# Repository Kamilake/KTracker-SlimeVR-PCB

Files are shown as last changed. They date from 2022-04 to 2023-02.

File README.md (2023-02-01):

# Move to the [FineMotion!](https://github.com/Kamilake/FineMotion-Tracker)
This repo is old and I created a new tracker. For non-maintenance purposes, go to:   
https://github.com/Kamilake/FineMotion-Tracker

# KTracker-SlimeVR-PCB
ESP8266 Attitude Tracker for SlimeVR

Full SMT PCB operating in MPU-6050 + QMC5883L 9DoF mode (or any breakout board compatible with GY-521)

Operate with all 5V chargers, including C to C PD chargers.

You can use it simply by ordering it from the fabricator

M.2 SSD size ultra-small form factor, Smallest size that can fit 18650!

FBT_Round_2022-Feb-21_12-32-22AM-000_CustomizedView14755583882_png - 복사본
KakaoTalk_20220223_222725417_01
KakaoTalk_20220223_222725417


KakaoTalk_20220420_084354356_01
KakaoTalk_20220726_093847052

## Available Battery

You can use any battery if you don't use the included modeling. or
1. 052050,052070,102050,102070 Size Li-Po (1000mAh) with JST PH 2.0mm Connector
2. 18650 battery (up to 4200mAh) with THT PIN 18650 Battery holder
3. 3x 1.5v battery (cannot be charged)

## Available Equipment 

## License
**This hardware is licensed under the CERN-OHL-P v2 license**, which is a permissive,
non-viral and non-reciprocal open hardware license. Unlike software licenses like
MIT and Apache 2.0, it better handles the nuances of hardware and protects both
the licensor and licensee from patent lawsuits.

**Unless you explicitly state otherwise, any contribution intentionally submitted
for inclusion in this work by you, shall be licensed as above, without any
additional terms or conditions.**

### Conveying notice of License
Note that as part of the CERN-OHL-P v2 license, recipients of manufactured
hardware must also receive notice of the above license. One such
method of conveying the notice is to include a link to the original source repo,
or printing "Licensed under CERN-OHL-P v2" on the PCB silkscreen. For more info,
see [here](https://ohwr.org/project/cernohl/wikis/Documents/CERN-OHL-version-2).

This is conceptually similar to the MIT/Apache 2.0 Licenses, where the original
license must still be included as a notice even when the source is modified and
subsequently relicensed under different terms.

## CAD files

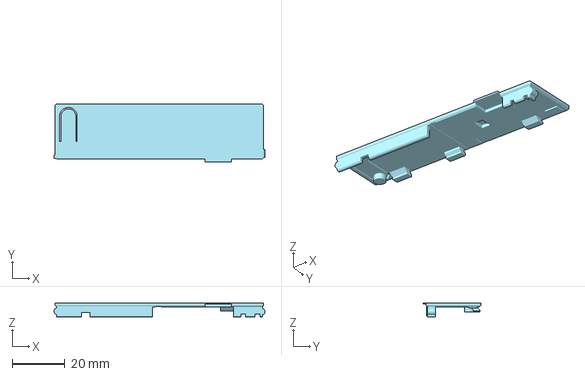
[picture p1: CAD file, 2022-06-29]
3D Models/FBT_Round2 v30 Cover.3mf
79.9 x 21.8 x 5.40 mm

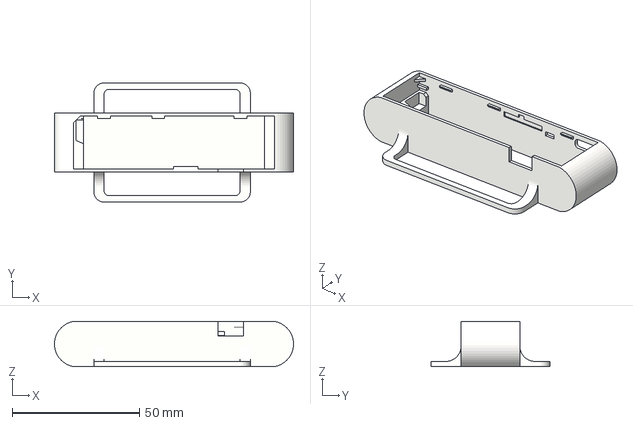
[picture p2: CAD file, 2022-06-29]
3D Models/FBT_Round2 v31 Chassis.3mf
93.8 x 46.8 x 17.7 mm

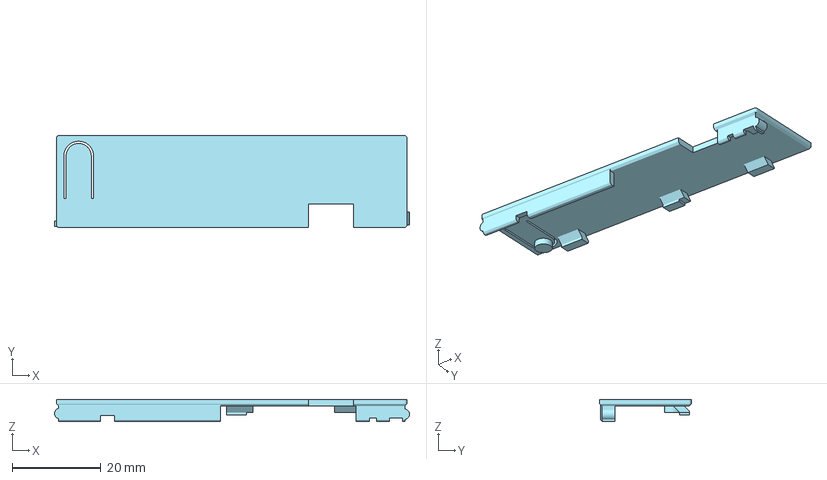
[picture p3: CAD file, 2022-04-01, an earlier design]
3D Models/FBT_Round2 v23 Cover.3mf
79.9 x 20.7 x 5.00 mm

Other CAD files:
3D Models/FBT_Round2 v23 Chassis.3mf

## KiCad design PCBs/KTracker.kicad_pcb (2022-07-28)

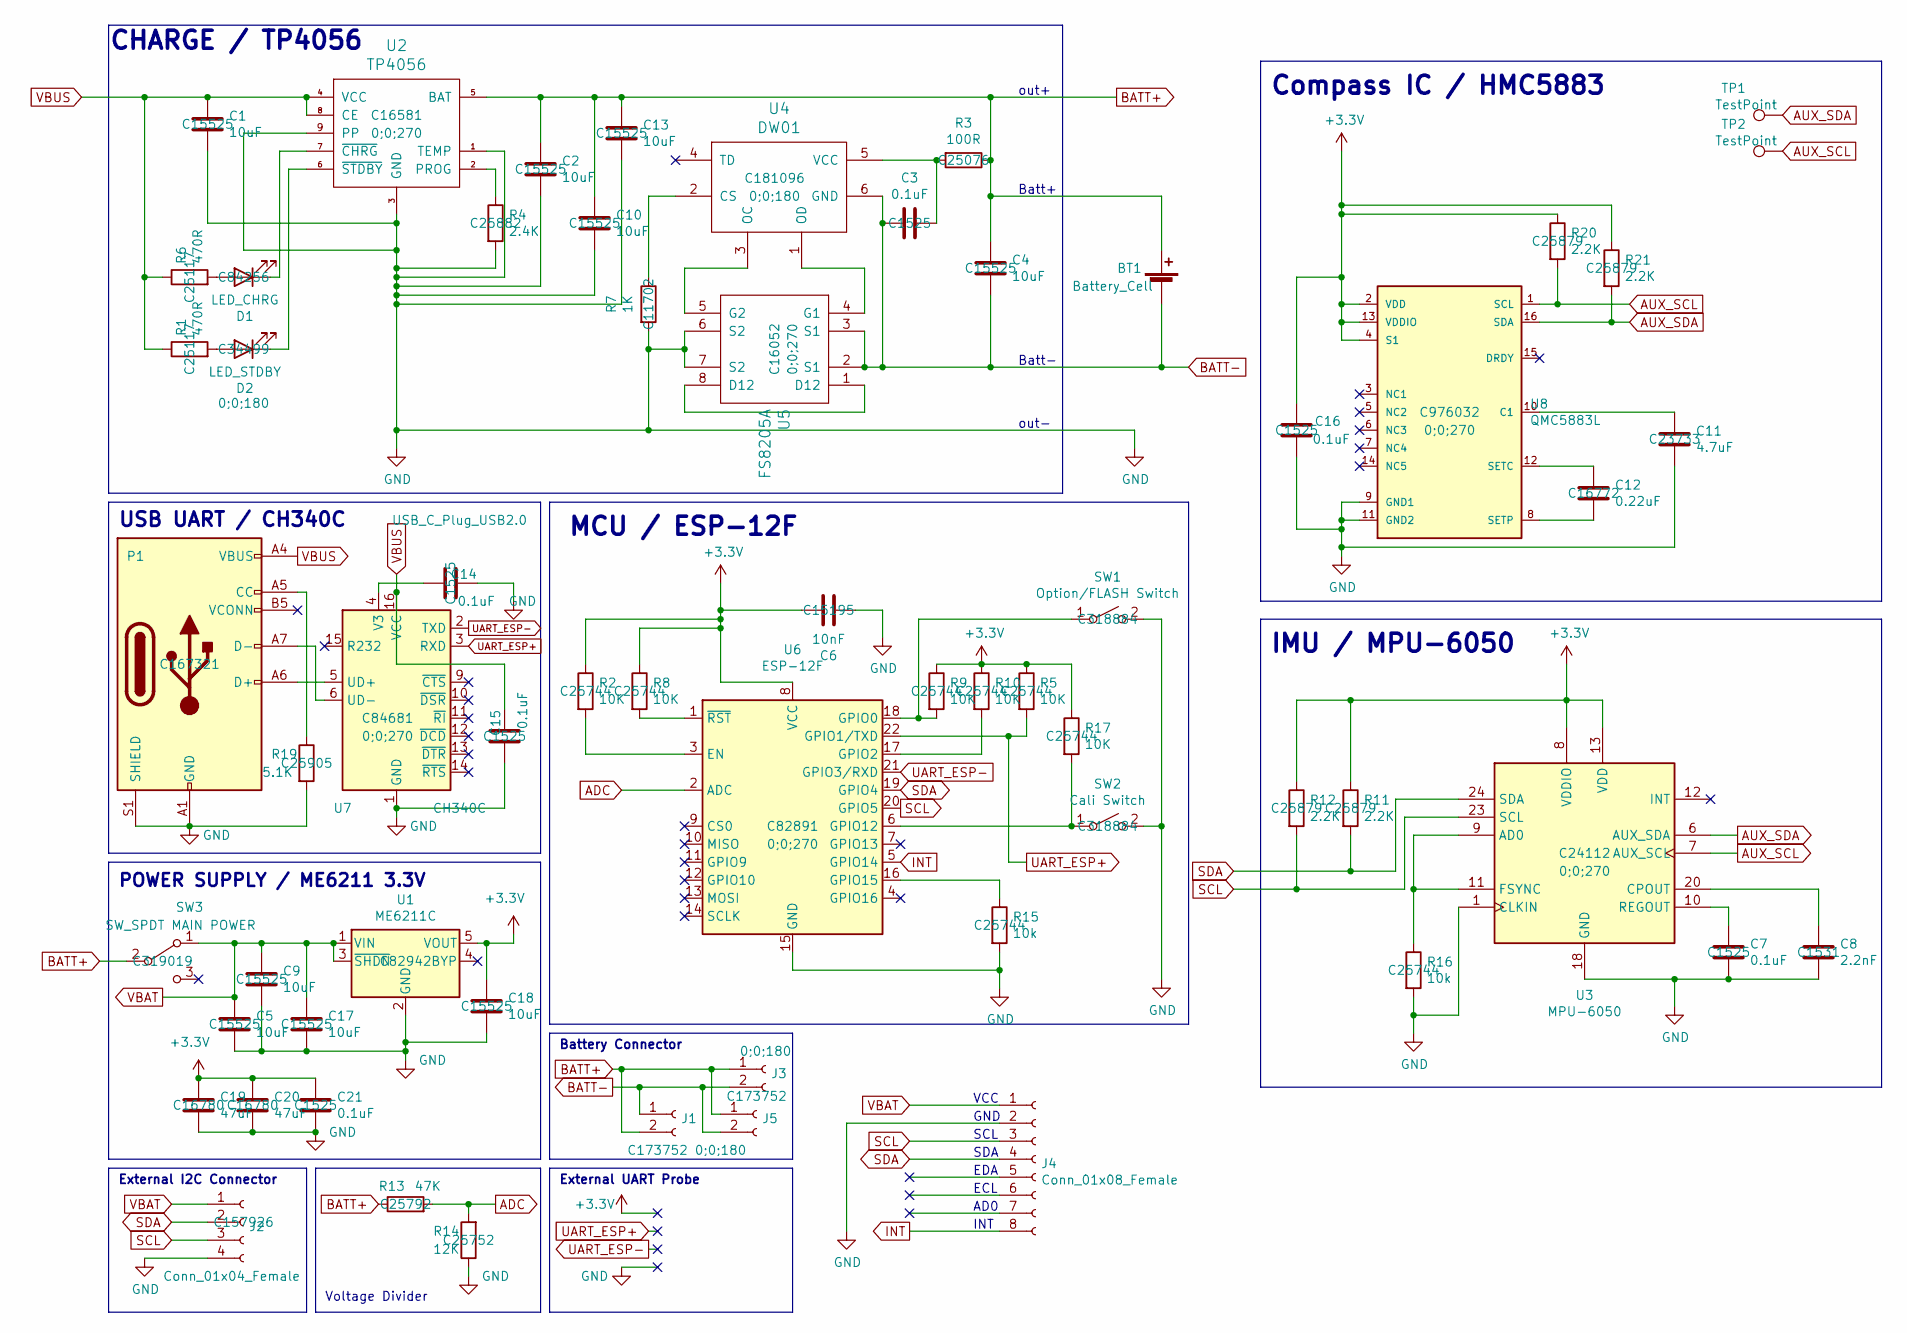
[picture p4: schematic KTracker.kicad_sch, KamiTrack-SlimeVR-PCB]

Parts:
BT1: Battery_Cell; BatteryHolder_MPD_BH-18650-PC2
C1, C2, C4, C5, C9, C10, C13, C17, C18: 10uF; C_0402_1005Metric; LCSC C15525
C3, C7, C14, C15, C16, C21: 0.1uF; C_0402_1005Metric; LCSC C1525
C6: 10nF; C_0402_1005Metric; LCSC C15195
C8: 2.2nF; C_0402_1005Metric; LCSC C1531
C11: 4.7uF; C_0402_1005Metric; LCSC C23733
C12: 0.22uF; C_0402_1005Metric; LCSC C16772
C19, C20: 47uF; C_0805_2012Metric; LCSC C16780
D1: LED_CHRG; LED_0805_2012Metric; LCSC C84256
D2: LED_STDBY; LED_0805_2012Metric; LCSC C34499
J1, J3: Conn_01x02_Female; JST_PH_S2B-PH-K_1x02_P2.00mm_Horizontal; LCSC C173752
J2: Conn_01x04_Female; JST_PH_S4B-PH-K_1x04_P2.00mm_Horizontal; LCSC C157926
J4: Conn_01x08_Female; PinSocket_1x08_P2.54mm_Vertical
J5: Conn_01x02_Female; MOLEX_532610271
P1: USB_C_Plug_USB2.0; USB_C_Receptacle_HRO_TYPE-C-31-M-12; LCSC C167321
R1, R6: 470R; R_0402_1005Metric; LCSC C25117
R2, R5, R8, R9, R10, R17: 10K; R_0402_1005Metric; LCSC C25744
R3: 100R; R_0402_1005Metric; LCSC C25076
R4: 2.4K; R_0402_1005Metric; LCSC C25882
R7: 1K; R_0402_1005Metric; LCSC C11702
R11, R12, R20, R21: 2.2K; R_0402_1005Metric; LCSC C25879
R13: 47K; R_0402_1005Metric; LCSC C25792
R14: 12K; R_0402_1005Metric; LCSC C25752
R15, R16: 10k; R_0402_1005Metric; LCSC C25744
R19: 5.1K; R_0402_1005Metric; LCSC C25905
SW1: Option/FLASH Switch; SW_SPST_SKQG_WithoutStem; LCSC C318884
SW2: Cali Switch; SW_SPST_SKQG_WithoutStem; LCSC C318884
SW3: SW_SPDT MAIN POWER; SW_SPDT_PCM12; LCSC C319019
TP1, TP2: TestPoint; TestPoint_Pad_D1.0mm
U1: ME6211C; SOT-23-5; LCSC C82942
U2: TP4056; HSOP-8-1EP_3.9x4.9mm_P1.27mm_EP2.41x3.1mm_ThermalVias; LCSC C16581
U3: MPU-6050; InvenSense_QFN-24_4x4mm_P0.5mm; LCSC C24112
U4: DW01; SOT-23-6_Handsoldering; LCSC C181096
U5: FS8205A; TSSOP-8_4.4x3mm_P0.65mm; LCSC C16052
U6: ESP-12F; ESP-12E; LCSC C82891
U7: CH340C; SOIC-16_3.9x9.9mm_P1.27mm; LCSC C84681
U8: QMC5883L; LGA-16_3x3mm_P0.5mm; LCSC C976032

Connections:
+3V3: C6.1, C16.2, C18.1, C19.1, C20.1, C21.1, R2.1, R5.1, R8.1, R9.1, R10.1, R11.1, R12.1, R17.1, R20.1, R21.1, U1.5 (VOUT), U3.8 (VDDIO), U3.13 (VDD), U6.8 (VCC), U8.2 (VDD), U8.4 (S1), U8.13 (VDDIO); also elsewhere on the board
ADC: R13.2, R14.2, U6.2 (ADC)
AUX_SCL: R20.2, TP2.1, U3.7 (AUX_SCL), U8.1 (SCL)
AUX_SDA: R21.2, TP1.1, U3.6 (AUX_SDA), U8.16 (SDA)
BATT+: BT1.1 (+), C2.1, C4.1, C10.1, C13.1, J1.2, J3.1, J5.1, R3.1, R13.1, SW3.2 (B), U2.5 (BAT)
BATT-: BT1.2 (-), C3.2, C4.2, J1.1, J3.2, J5.2, U4.6 (GND), U5.2 (S1), U5.3 (S1)
GND: C1.2, C2.2, C5.2, C6.2, C7.2, C8.2, C9.2, C10.2, C11.2, C13.2, C14.2, C15.1, C16.1, C17.2, C18.2, C19.2, C20.2, C21.2, J2.4, J4.2, P1.A1 (GND), P1.A12 (GND), P1.B1 (GND), P1.B12 (GND), P1.S1 (SHIELD), R4.2, R7.2, R14.1, R15.2, R16.2, R19.2, SW1.2 (B), SW2.2 (B), U1.2 (GND), U2.1 (TEMP), U2.3 (GND), U2.9 (PP), U3.1 (CLKIN), U3.18 (GND), U5.6 (S2), U5.7 (S2), U6.15 (GND), U7.1 (GND), U8.9 (GND1), U8.11 (GND2); also elsewhere on the board
INT: J4.8, U6.5 (GPIO14)
unnamed: C3.1, R3.2, U4.5 (VCC)
unnamed: C7.1, U3.10 (REGOUT)
unnamed: C8.1, U3.20 (CPOUT)
unnamed: C11.1, U8.10 (C1)
unnamed: C12.1, U8.12 (SETC)
unnamed: C12.2, U8.8 (SETP)
unnamed: C14.1, U7.4 (V3)
unnamed: D1.1 (K), U2.7 (~CHRG)
unnamed: D1.2 (A), R6.2
unnamed: D2.1 (K), U2.6 (~STDBY)
unnamed: D2.2 (A), R1.2
unnamed: P1.A5 (CC), R19.1
unnamed: P1.A6 (D+), U7.5 (UD+)
unnamed: P1.A7 (D-), U7.6 (UD-)
unnamed: R2.2, U6.3 (EN)
unnamed: R4.1, U2.2 (PROG)
unnamed: R7.1, U4.2 (CS)
unnamed: R8.2, U6.1 (~RST)
unnamed: R9.2, SW1.1 (A), U6.18 (GPIO0)
unnamed: R10.2, U6.17 (GPIO2)
unnamed: R15.1, U6.16 (GPIO15)
unnamed: R16.1, U3.9 (AD0), U3.11 (FSYNC)
unnamed: R17.2, SW2.1 (A), U6.6 (GPIO12)
unnamed: U4.1 (OD), U5.4 (G1)
unnamed: U4.3 (OC), U5.5 (G2)
unnamed: U5.1 (D12), U5.8 (D12)
SCL: J2.3, J4.3, R12.2, U3.23 (SCL), U6.20 (GPIO5)
SDA: J2.2, J4.4, R11.2, U3.24 (SDA), U6.19 (GPIO4)
UART_ESP+: R5.2, U6.22 (GPIO1/TXD), U7.3 (RXD)
UART_ESP-: U6.21 (GPIO3/RXD), U7.2 (TXD)
VBAT: C5.1, C9.1, C17.1, J2.1, J4.1, SW3.1 (A), U1.1 (VIN), U1.3 (~SHDN)
VBUS: C1.1, C15.2, P1.A4 (VBUS), P1.A9 (VBUS), P1.B4 (VBUS), P1.B9 (VBUS), R1.1, R6.1, U2.4 (VCC), U2.8 (CE), U7.16 (VCC)

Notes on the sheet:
Voltage Divider
Batt-
External UART Probe
MCU / ESP-12F
External I2C Connector
AD0
IMU / MPU-6050
Compass IC / HMC5883
POWER SUPPLY / ME6211 3.3V
ECL
out+
GND
EDA
VCC
SDA
INT
Batt+
CHARGE / TP4056
USB UART / CH340C
Battery Connector
out-
SCL

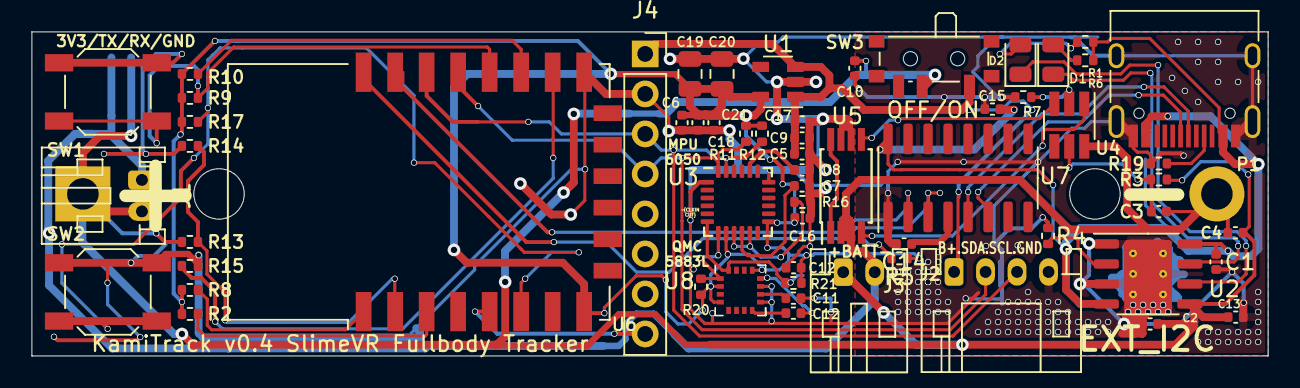
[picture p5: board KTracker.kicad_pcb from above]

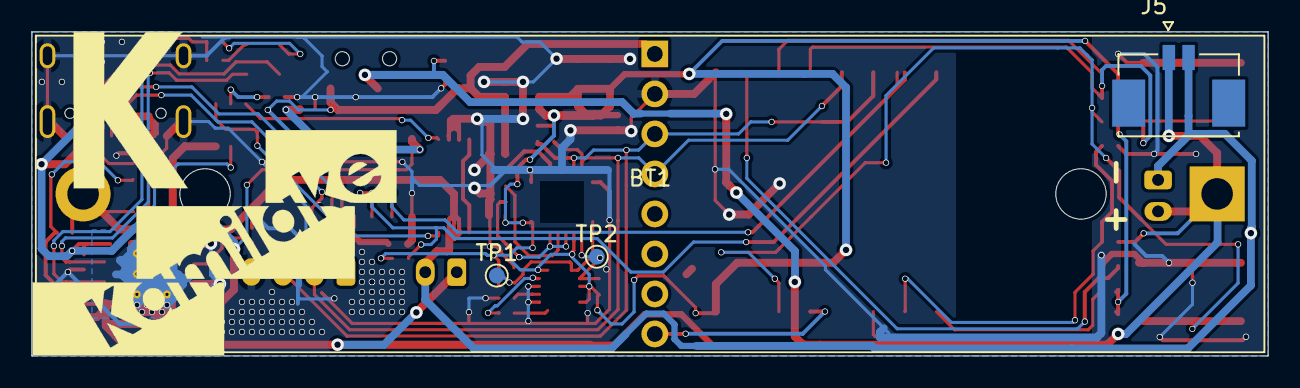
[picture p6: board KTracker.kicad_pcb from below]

Board: 2 copper layers, 78.5 x 20.6 mm, 64 parts (4 on the bottom side), 40 nets.

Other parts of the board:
C12#2: 0.1uF; C_0402_1005Metric

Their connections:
+3V3: C12#2.1; also elsewhere on the board
GND: C12#2.2; also elsewhere on the board

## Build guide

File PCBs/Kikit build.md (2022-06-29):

# Custom assembly using Kikit

## Panalize and Fab
```batch
kikit panelize ^
    -p :jlcTooling ^
    --layout "grid; rows: 5; cols: 10;" ^
    --source "tolerance: 1000mm" ^
    --tabs full ^
    --cuts vcuts ./KamiTrack.kicad_pcb ^
    KamiTrack_panel.kicad_pcb

kikit fab jlcpcb ^
    --assembly ^
    --schematic ./KamiTrack.kicad_sch ^
    --ignore J1 ^
    --no-drc ./KamiTrack_panel.kicad_pcb ^
    ./fab
```

## Only Fab

### Using internal MPU-6050 and bottom Lipo
```batch
kikit fab jlcpcb ^
    --assembly ^
    --schematic ./KamiTrack.kicad_sch ^
    --ignore BT1,J3,J4,J5 ^
    --no-drc ./KamiTrack.kicad_pcb ^
    "./Gerber/Using internal MPU-6050"

```

### Using GY-521 and bottom Lipo
```batch
kikit fab jlcpcb ^
    --assembly ^
    --schematic ./KamiTrack.kicad_sch ^
    --ignore U8,U3,R20,R21,C16,C12,C11,R12,R11,BT1,J3,J4,J5 ^
    --no-drc ./KamiTrack.kicad_pcb ^
    "./Gerber/Using GY-521"

```

### Using GY-521 and 18650
```batch
kikit fab jlcpcb ^
    --assembly ^
    --schematic ./KamiTrack.kicad_sch ^
    --ignore U8,U3,R20,R21,C16,C12,C11,R12,R11,J1,J3,J4,J5 ^
    --no-drc ./KamiTrack.kicad_pcb ^
    "./Gerber/Using GY-521"

```

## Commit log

2022-04-01 Add 3D Models
    [FBT_Round2 v23 Chassis.3mf, FBT_Round2 v23 Cover.3mf]
2022-04-06 pcb thickness 1.6->1.2
    [KamiTrack.kicad_pcb]
2022-04-07 Added sheet description
    [KamiTrack.kicad_sch]
2022-06-29 custom assembly guide
2022-06-29 Left side Lipo
2022-06-29 Standby LED Change to C34499
    [KamiTrack.kicad_sch]
2022-06-29 Rename to kamitrack
    [KamiTrack.kicad_pcb]
2022-07-28 add JLCPCB_CORRECTION
    [KamiTrack.kicad_pcb, KamiTrack.kicad_sch]
2022-07-28 add more JLCPCB_CORRECTION
    [KamiTrack.kicad_sch]
2022-07-28 THIS IS VERY CURRECT JLCPCB_CORRECTION I SWEAR
    [KamiTrack.kicad_sch]

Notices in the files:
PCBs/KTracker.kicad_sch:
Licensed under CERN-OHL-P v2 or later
